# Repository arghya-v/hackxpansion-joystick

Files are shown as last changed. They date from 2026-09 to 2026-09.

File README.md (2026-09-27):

# hackxpansion-joystick

The joystick module for hackxpansion!
<br/>
**Crates:** pkg:cargo/JoystickHackx@0.1.0
# Images
case
pcb
schematic

### Pin Mapping

| Function | Xpanse GPIO  |
| --- | --- |
| X axis | GPIO7 / ADC0 |
| Y axis | GPIO8 / ADC1 |
| Center button | GPIO9 |

See the [Xpanse API docs](https://docs.rs/xpanse-api/latest/xpanse_api/index.html)

The joystick axes are connected as potentiometers between 3.3 V and GND, with the wipers connected to the ADC pins.

---

This was all possible thanks to [Hackspansion: A hackclub YSWS](http://hackxpansion.hackclub.com/)

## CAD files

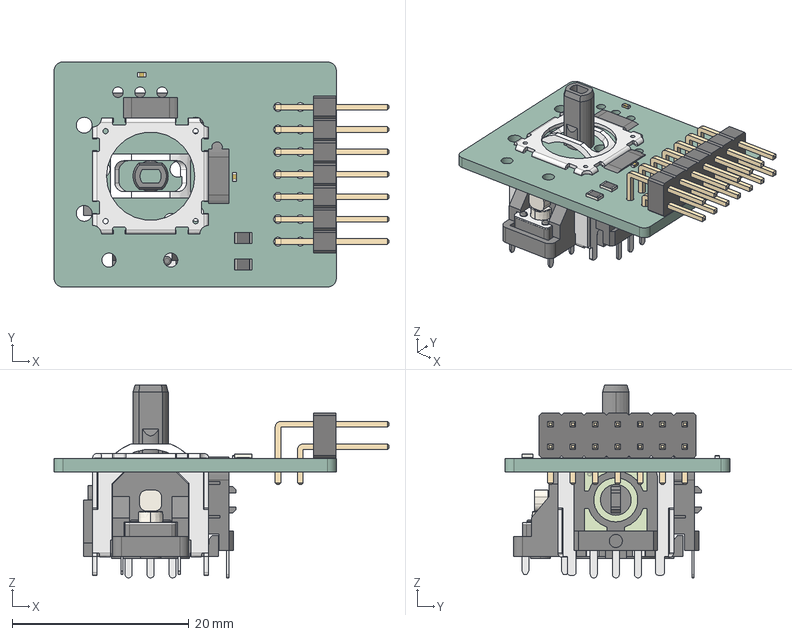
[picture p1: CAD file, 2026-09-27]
cad/Joystick.step
38.0 x 25.5 x 21.8 mm
R_0805_2012Metric x 2
C0402_L1.0-W0.5-H0.5 x 2
SW-TH_RKJXV1224005
PinHeader_2x07_P254mm_Horizontal
JoyBB12_PCB

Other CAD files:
cad/Joystick-case.f3z

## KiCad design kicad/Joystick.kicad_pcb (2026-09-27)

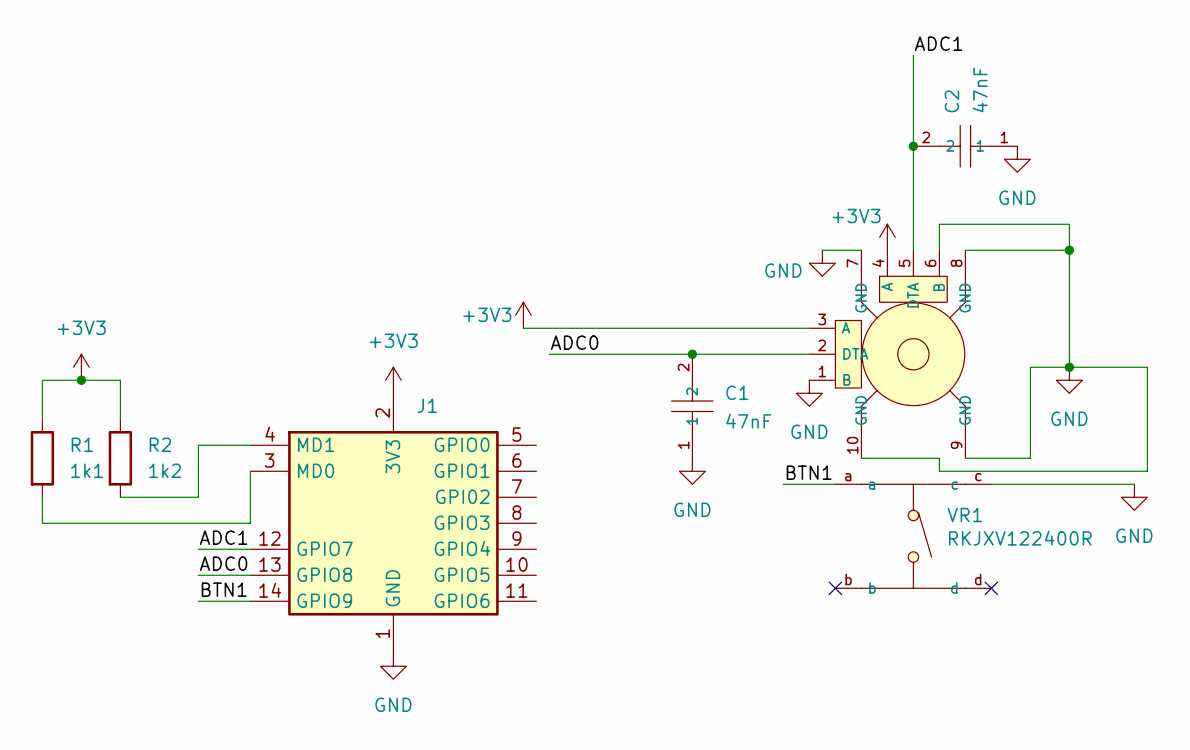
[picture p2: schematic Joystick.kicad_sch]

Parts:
C1, C2: 47nF; C338148_C0402; LCSC C338148
J1: Male_Module
R1: 1k1; R_0805_2012Metric_Pad1.20x1.40mm_HandSolder
R2: 1k2; R_0805_2012Metric_Pad1.20x1.40mm_HandSolder
VR1: RKJXV122400R; C918854_SW-TH_RKJXV1224005; LCSC C918854

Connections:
+3V3: J1.2 (3V3), R1.1, R2.1, VR1.3 (A), VR1.4 (A)
/ADC0: C1.2, J1.13 (GPIO8), VR1.2 (DTA)
/ADC1: C2.2, J1.12 (GPIO7), VR1.5 (DTA)
/BTN1: J1.14 (GPIO9), VR1.a
GND: C1.1, C2.1, J1.1 (GND), VR1.1 (B), VR1.6 (B), VR1.7 (GND), VR1.8 (GND), VR1.9 (GND), VR1.10 (GND), VR1.c
unnamed: J1.3 (MD0), R1.2
unnamed: J1.4 (MD1), R2.2

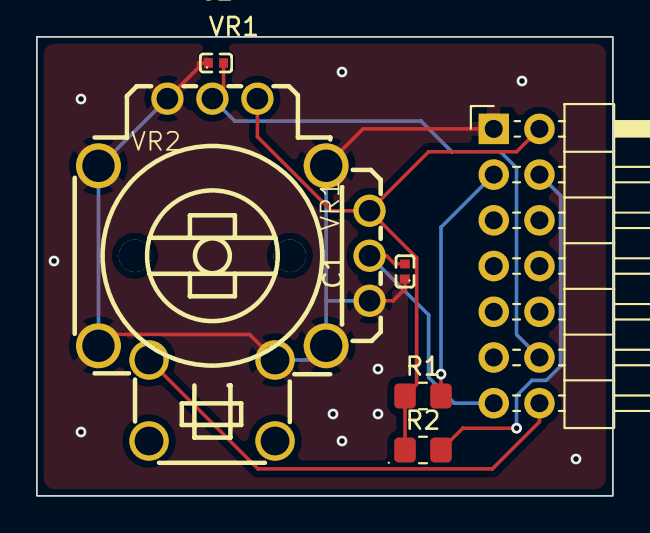
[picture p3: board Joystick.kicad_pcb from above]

Board: 2 copper layers, 32.0 x 25.5 mm, 6 parts (0 on the bottom side), 7 nets.

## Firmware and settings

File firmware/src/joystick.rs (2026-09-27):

use alloc::boxed::Box;

use core::{
    future::Future,
    pin::Pin,
};

use embassy_rp::{
    Peri,
    adc::AdcPin,
    gpio::AnyPin,
};

use xpanse_api::interfaces::{
    adc::{self, AdcError},
    buttons::{A, Button, pin_button},
};

trait AdcAxis: Send {
    fn read<'a>(
        &'a mut self,
    ) -> Pin<Box<dyn Future<Output = Result<u16, AdcError>> + Send + 'a>>;
}

struct PinAxis<P>
where
    P: AdcPin + Send + 'static,
{
    pin: Peri<'static, P>,
}

impl<P> AdcAxis for PinAxis<P>
where
    P: AdcPin + Send + 'static,
{
    fn read<'a>(
        &'a mut self,
    ) -> Pin<Box<dyn Future<Output = Result<u16, AdcError>> + Send + 'a>> {
        Box::pin(async move {
            adc::read_adc_pin(
                &mut self.pin,
                embassy_rp::gpio::Pull::None,
            )
            .await
        })
    }
}

pub struct Joystick {
    x: Box<dyn AdcAxis>,
    y: Box<dyn AdcAxis>,
    button: Box<dyn Button<A>>,
}

impl Joystick {
    pub fn new<X, Y>(
        x: Peri<'static, X>,
        y: Peri<'static, Y>,
        button: Peri<'static, AnyPin>,
    ) -> Self
    where
        X: AdcPin + Send + 'static,
        Y: AdcPin + Send + 'static,
    {
        Self {
            x: Box::new(PinAxis { pin: x }),
            y: Box::new(PinAxis { pin: y }),
            button: pin_button::<A>(button),
        }
    }

    pub async fn read_x(&mut self) -> Result<u16, AdcError> {
        self.x.read().await
    }

    pub async fn read_y(&mut self) -> Result<u16, AdcError> {
        self.y.read().await
    }

    pub async fn read(&mut self) -> Result<(u16, u16), AdcError> {
        let x = self.read_x().await?;
        let y = self.read_y().await?;
        Ok((x, y))
    }

    pub fn is_pressed(&self) -> bool {
        self.button.is_pressed()
    }

    pub async fn wait_for_pressed(&mut self) {
        self.button.wait_for_pressed().await;
    }
}

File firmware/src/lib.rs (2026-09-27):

#![no_std]

extern crate alloc;

mod joystick;

use joystick::Joystick;

use xpanse_api::{
    bus::allocator::BusAllocator,
    driver::{Driver, DriverError, DriverMeta},
    gpio_bank::{BankPins, GpioBank},
    metadata::{ModuleDetectResistor, ModuleID, ModuleSlot},
    registry::Registry,
};

pub struct JoystickDriver;

impl DriverMeta for JoystickDriver {
    const ID: ModuleID = ModuleID {
        md0: ModuleDetectResistor::R1K1,
        md1: ModuleDetectResistor::R1K2,
    };
}

impl<G: BankPins> Driver<G> for JoystickDriver {
    async fn create(
        gpio_bank: GpioBank<G>,
        slot: ModuleSlot,
        registry: &mut Registry,
        bus_allocator: &mut BusAllocator,
    ) -> Result<(), DriverError> {
        let joystick = Joystick::new(
            gpio_bank.gpio7,
            gpio_bank.gpio8,
            gpio_bank.gpio9.into(),
        );

        registry.register(
            slot,
            JoystickDriver::ID,
            joystick,
        );

        let _ = bus_allocator;

        Ok(())
    }
}

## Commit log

2026-09-27 done driver
2026-09-27 Enhance README with joystick module details
    Added detailed information about the joystick module, including images, pin mapping, and connection details.
2026-10-04 Add price and additional items to bom.csv
2026-10-11 Modify BOM with new resistor values and totals
    Updated resistor values and part numbers in BOM.
2026-10-11 Enhance README with joystick details and BOM
    Added detailed explanation of joystick functionality and updated BOM table.
2026-10-18 Update image links in README.md
    Updated image links for case and PCB in README.
